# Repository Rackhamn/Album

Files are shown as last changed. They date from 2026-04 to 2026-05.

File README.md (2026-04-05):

<picture align="center">
  <source media="(prefers-color-scheme: dark)" srcset="/img/Album_logo_demo_dark.png">
  <source media="(prefers-color-scheme: light)" srcset="/img/Album_logo_demo_light.png">
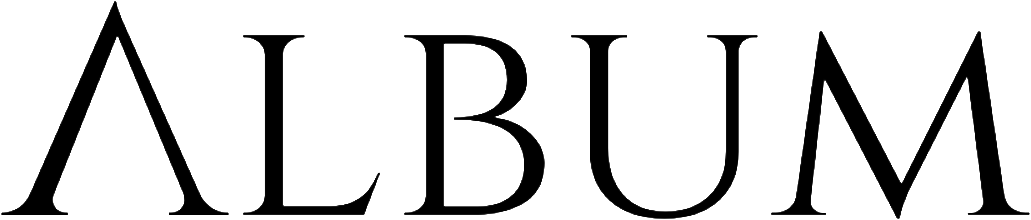
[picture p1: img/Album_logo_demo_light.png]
[Album Logo Demo]
  
</picture>

# ALBUM
Album is a handwired 36-key split keyboard with a custom firmware for the Atmega32u4 MCU.  
> Specifically Adafriut's ItsyBitsy Atmega32u4 16MHz 5V version found [here](https://www.adafruit.com/product/3677).  
  
It has a column-stagger with each half having two thumb keys and a [TOTEM](https://github.com/GEIGEIGEIST/TOTEM) inspired pinky key.  
The inital version did have a significant splay on the outer columns and the thumb keys, however my 3D printer had enough issues with layer shifting and thus I had to simplify it for V1.  
  
Album firmware currently runs the master code on the `LEFT` and the slave on the `RIGHT`.  
Master can be connected to any computer over the Atmega32u4 Micro-B port.  
The master and the slave parts can be connected over the TRRS jack.  
  
The Album firmware does not plan to rival others like [QMK](https://github.com/qmk/qmk_firmware), instead it was a challenging but fun process to plan and build out the features that I personally wanted to use.  
A previous `DEMO` version used a single 3x3 macro-pad style keyboard and a [VIAL](https://github.com/vial-kb/vial-qmk)-like keymap updater (through the USB-HID Vendor Reports) that does not need to compile or re-flash the firmware just to update a single keymap value change. It recieved a correct HID Report in a format according to a very simple protocol and overwrote the keymap in `SRAM` but also the stored keymap in `EEPROM`.  
*Very nice*.  
  
I am working on the new version for the V1 release and so far it seems very promising!  

## On the Source  
This is a final project for an __IoT- and Embedded Systems Degree__, the final source will be published at the end of the project.  
The source code will be come with the corresponding dependencies and build scripts for compiling everything along with the USB layer/keymap/macro updater scripts.  
  
## Case and Materials  
The `STL` files can be found [here](/case/).  
The bill-of-materials can be found here `link`.  
  
## Photos  
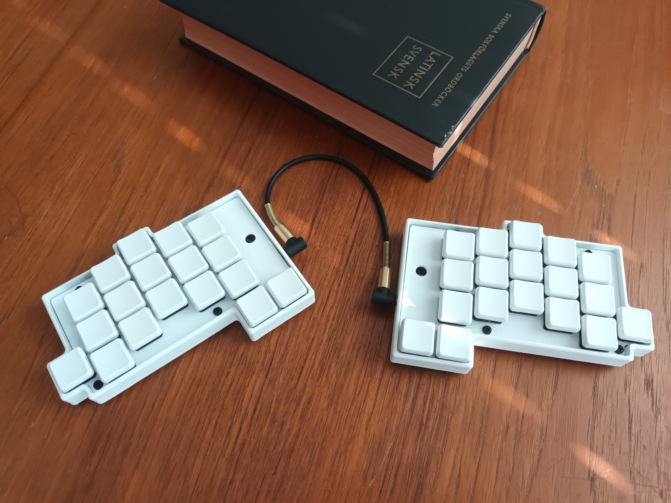
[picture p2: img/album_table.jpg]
Album on Wooden Table
  
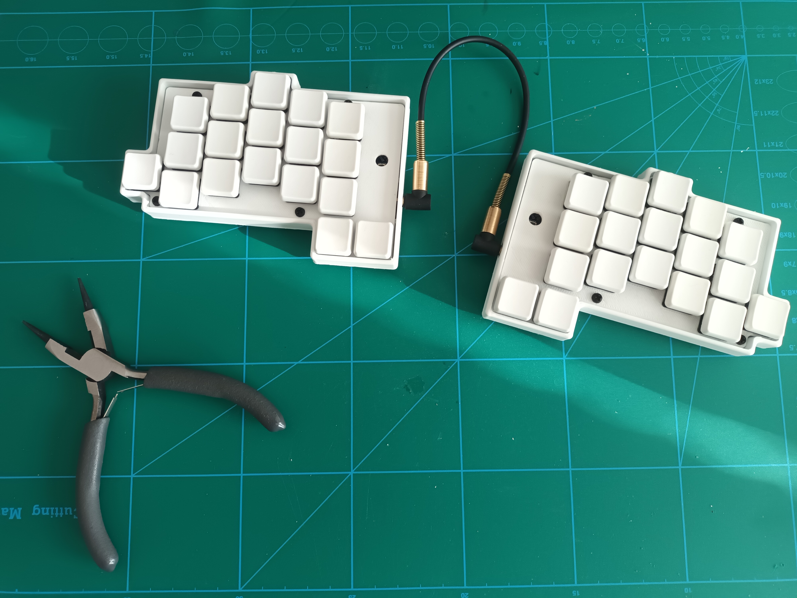
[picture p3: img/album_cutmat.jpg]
Album on Green Cutting Mat
  

## Credits
Really cool initial inspiration from the TOTEM keyboard in terms of visual design.  
[TOTEM Keyboard by GEIGEIGEIST](https://github.com/GEIGEIGEIST/TOTEM)  

Fantastic website with lots of references for keyboard design!  
[kbd.news](https://kbd.news)  
  
Great jumping off point to be able to start working on a deeper implementation of USB-HID on the Atmega32u4.  
[KMani314's Atmega32u4 HID Keyboard](https://github.com/kmani314/ATMega32u4-HID-Keyboard)  
  
Font is Cinzel-Regular by ndiscovered, you can download it [here](https://www.1001fonts.com/cinzel-font.html)  

Switch and Keycaps:  
[Switch (Kailh Choc low-profile white/clicky)](https://chosfox.com/products/kailh-chocs)  
[Keycaps (Choc low-profile 1U white)](https://chosfox.com/products/chocfox-cfx-choc-keycaps)  
> If you are going to make your own, I would recommend using slient tactile switches instead. The clicky ones are slightly echo-y in the V1 case unless you add support foam etc...

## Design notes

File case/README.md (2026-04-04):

# About the Case and Plate Housing
  
The case is built of two pieces, one bottom-side and a inner-top part.  
This case was 3D printed with a PLA printer at 4mm with 'regular' white PLA.  
I would recommend that you use a resin printer for cleaner results.  
> My printer did have issues with the wall sizes, and a couple of inner supports got broken during the printing process.  
  
To get either the left or right version, you can put them into you slicer of choice and invert the X-axis of the models.  

*[images here]*

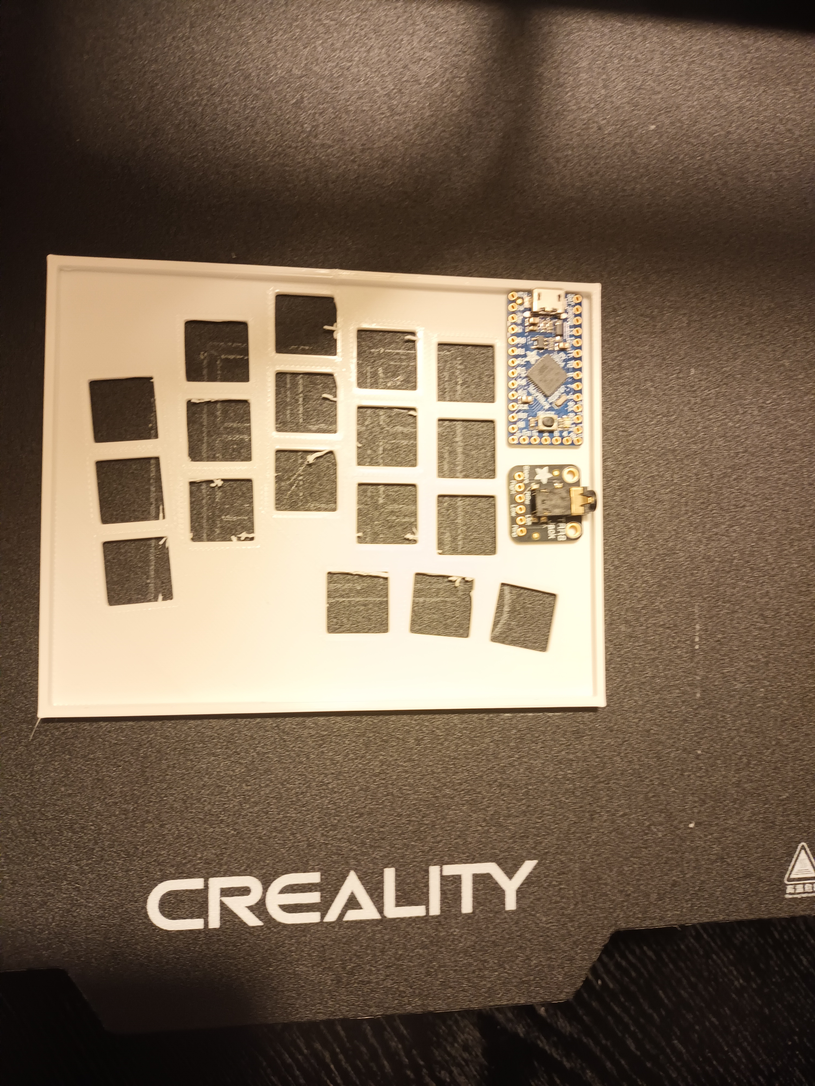
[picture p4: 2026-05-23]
img/proto/layout_pv0.jpg

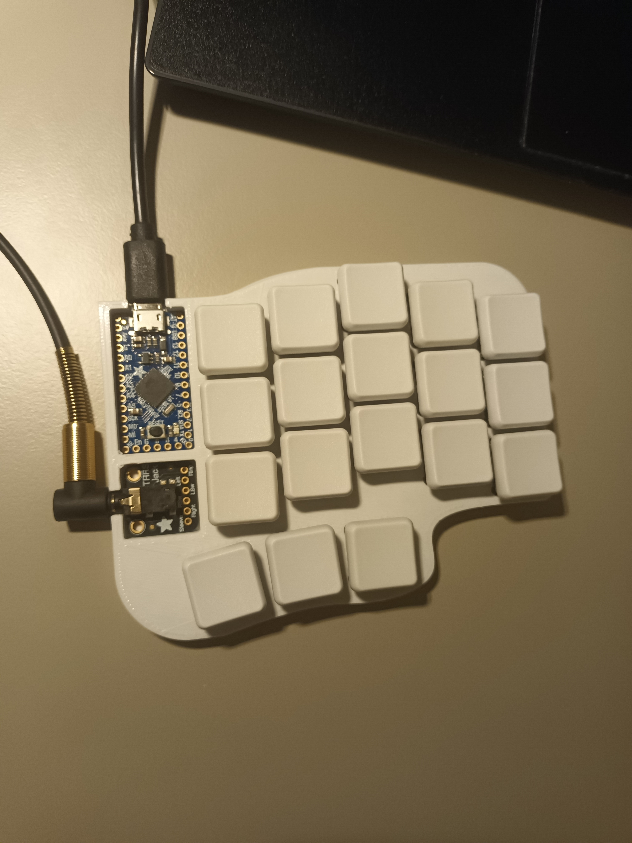
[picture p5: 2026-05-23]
img/proto/layout_pv1.jpg

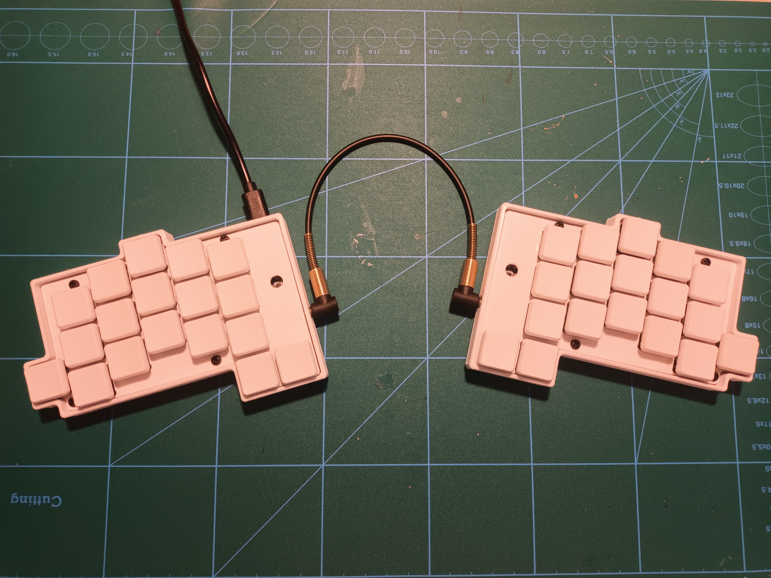
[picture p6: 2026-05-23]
img/proto/final_conn.jpg

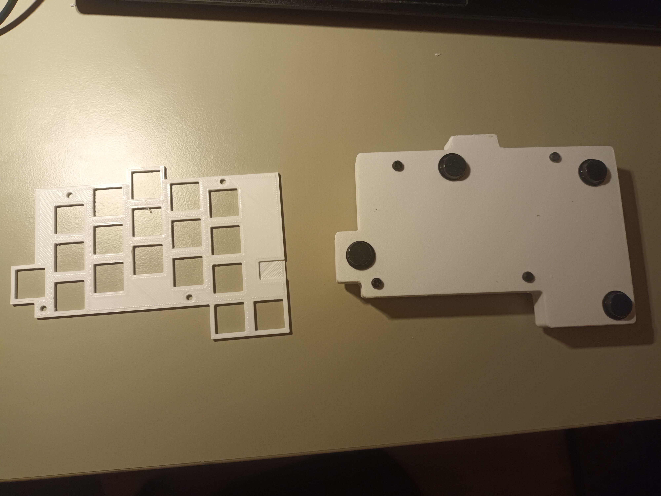
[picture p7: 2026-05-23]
img/proto/layout_pv4_case.jpg

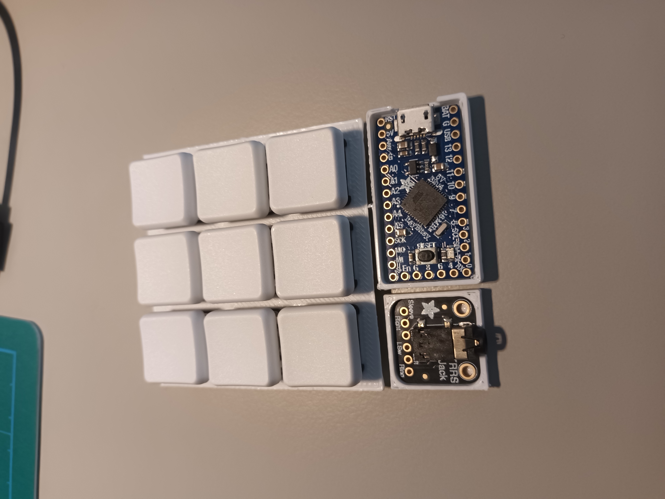
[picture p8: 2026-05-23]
img/proto/layout_pvx.jpg

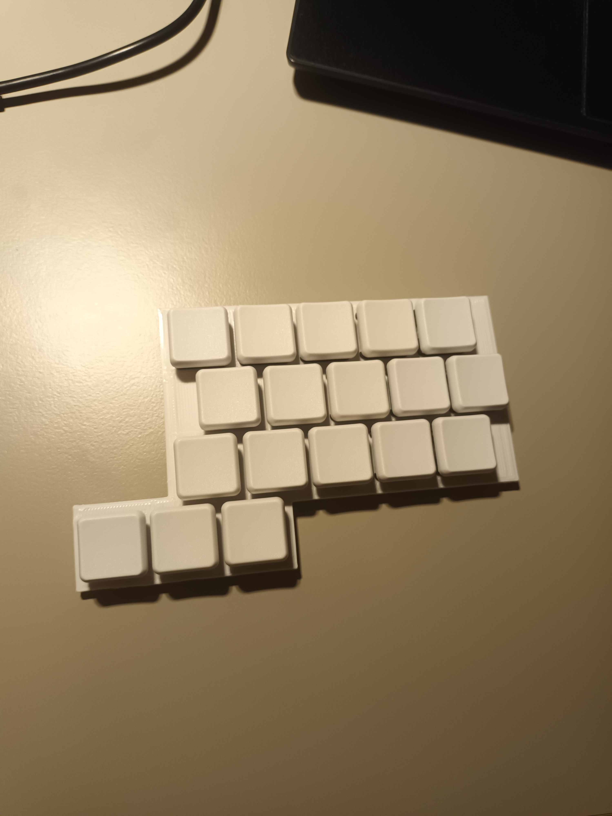
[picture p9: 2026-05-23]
img/proto/layout_pv3.jpg

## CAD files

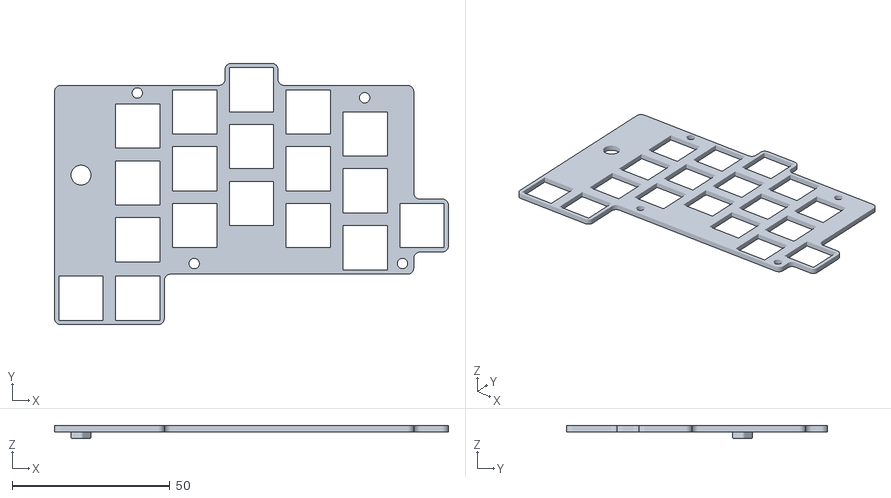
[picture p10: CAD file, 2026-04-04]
case/album_plate.stl
124.8 x 82.8 x 4.00

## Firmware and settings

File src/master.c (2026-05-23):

#ifndef F_CPU
#define F_CPU 16000000UL
#endif

#include <avr/io.h>
#include <util/delay.h>
#include <avr/interrupt.h>
#include <avr/eeprom.h>
#include <string.h> // memcpy

#include "types.h" // todo: replace NintM_t with NM
#include "macros.h"
#include "defs.h"

#include "usb.h"
#include "usb.c"

#include "crc8.c"

#include "keycodes.h"
#include "keybase.h"

// for both halfs!
u8 matrix[KEYMAP_LAYER_SIZE] = { 0 };
u8 last_matrix[KEYMAP_LAYER_SIZE] = { 0 };

#define NUM_LAYERS	2
#define KEYBOARD_DATA_LAYERS \
	[0]{																															\
	/* Base Layer: */																											\
		/* Master */																											\
		K(KC_Q), K(KC_W), K(KC_E), K(KC_R), K(KC_T),																			\
		K(KC_A), K(KC_S), K(KC_D), K(KC_F), K(KC_G),																			\
		K(KC_Z), K(KC_X), K(KC_C), K(KC_V), K(KC_B),																			\
		K(KC_Y), 0x00, 0x00, K(KC_O), DK(KEY_DEV_LAYER_INC),																	\
																																\
		/* Slave */																												\
		K(KC_Q), K(KC_W), K(KC_E), KM(KC_8, MOD_RIGHT, MOD_ALT), KM(KC_9, MOD_RIGHT, MOD_ALT),									\
		K(KC_A), K(KC_S), K(KC_D), K(KC_F), K(KC_G),																			\
		K(KC_Z), K(KC_X), K(KC_C), K(KC_V), K(KC_B),																			\
		DK(KEY_DEV_LAYER_DEC), K(KC_U), 0x00, 0x00, K(KC_P)																		\
	},																															\
	[1]{																															\
	/* Alt Layer: */																											\
		/* Master */																											\
		M(KC_MEDIA_BRIGHTNESS_DOWN), M(KC_MEDIA_BRIGHTNESS_UP), M(KC_MEDIA_MUTE), M(KC_MEDIA_VOL_DOWN), M(KC_MEDIA_VOL_UP),		\
		M(KC_MEDIA_BRIGHTNESS_MIN), K(KC_MEDIA_BRIGHTNESS_MAX), 0x00, M(KC_MEDIA_PLAY_PAUSE), 0x00,								\
		M(0xFF), K(KC_F), K(KC_J), K(KC_K), K(KC_L),																			\
		K(KC_Y), 0x00, 0x00, K(KC_O), DK(KEY_DEV_LAYER_INC),																	\
																																\
		/* Slave */																												\
		K(KC_Q), K(KC_W), K(KC_E), KM(KC_8, MOD_RIGHT, MOD_ALT), KM(KC_9, MOD_RIGHT, MOD_ALT),									\
		K(KC_A), K(KC_S), K(KC_D), K(KC_F), K(KC_G),																			\
		K(KC_Z), K(KC_X), K(KC_C), K(KC_V), K(KC_B),																			\
		DK(KEY_DEV_LAYER_DEC), K(KC_U), 0x00, 0x00, K(KC_P)																		\
	}

keyval_t matrix_vals[NUM_LAYERS][KEYMAP_LAYER_SIZE] = {
	KEYBOARD_DATA_LAYERS
};

// todo: rebuild into keyval_t data
typedef struct {
	u8 layer_index;
	u8 key_index;
	u16 repeat_ms;
	u32 last_sent_ms;
} hold_repeat_key_t;

// maybe add a minimum-hold time req. before we start to do the thing!
hold_repeat_key_t hold_repeat_keys[] = {
	{ 1, 3, 250, 0 },
	{ 1, 4, 250, 0 }
};
#define NUM_HOLD_REPEAT_KEYS (sizeof(hold_repeat_keys) / sizeof(hold_repeat_key_t))

hold_repeat_key_t * get_hold_repeat_key(u8 layer, u8 key) {
	for(u8 i = 0; i < NUM_HOLD_REPEAT_KEYS; i++) {
		if(hold_repeat_keys[i].layer_index == layer && hold_repeat_keys[i].key_index == key) {
			return &hold_repeat_keys[i];
		}
	}
	return NULL;
}

typedef struct keyboard_s {
	u8 num_layers;
	keyval_t (*map)[KEYMAP_LAYER_SIZE];

	// state
	u8 layer_index;
} keyboard_t;

keyboard_t keyboard = {
	.num_layers = NUM_LAYERS, // sizeof(matrix_vals)/sizeof(matrix_vals[0]),
	.map = matrix_vals,
	.layer_index = 0
};

// TODO: not active in current version 0.9
typedef struct __attribute__((packed)) {
	u8 magic;
	keyval_t keys[NUM_LAYERS][KEYMAP_LAYER_SIZE];
} keymap_config_t;

keymap_config_t ee_keymap EEMEM = {
	.magic = EEPROM_MAGIC,
	.keys = { KEYBOARD_DATA_LAYERS }
};

#if 0
keymap_config_t rt_keymap = {
	.magic = EEPROM_MAGIC,
	.keys = { KEYBOARD_DATA_LAYERS }
};

void load_keymap(void) {
	eeprom_read_block(&rt_keymap, &ee_keymap, sizeof(keymap_config_t));
	// eeprom_read_block(&rt_keymap, (const void*)EEPROM_ADDR, sizeof(keymap_config_t));

	#if 1
	if(rt_keymap.magic != EEPROM_MAGIC) {
		// TODO: handle both halfs
		memcpy(rt_keymap.keys, matrix_vals, NUM_LAYERS * KEYMAP_LAYER_SIZE);
		rt_keymap.magic = EEPROM_MAGIC;
		eeprom_write_block(&rt_keymap, &ee_keymap, sizeof(keymap_config_t));
		// eeprom_write_block(&rt_keymap, (void*)EEPROM_ADDR, sizeof(keymap_config_t));
	}
	#endif
	
	memcpy(matrix_vals, rt_keymap.keys, NUM_LAYERS * KEYMAP_LAYER_SIZE);
}

#if 0
// TODO: make eeprom writing be per-iteration (partially deffered)
// so write one byte per iteration instead of blocking by writing all at once?
void handle_hid_feature(void) {
	// return;

	if(!vendor_out_ready) { 
		return; 
	} else {
		vendor_out_ready = 0;
	}

	if(vendor_out_buf[0] != EEPROM_MAGIC) {
		return;
	}

	for(u8 i = 0; i < KEYMAP_LAYER_SIZE; i++) {
		rt_keymap.keys[i] = vendor_out_buf[i + 1];
	}

	memcpy(matrix_vals, rt_keymap.keys, KEYMAP_LAYER_SIZE);
	eeprom_write_block(&rt_keymap, &ee_keymap, sizeof(keymap_config_t));
}
#endif
#endif

void uart_init(void) {
	ENABLE_INPUT(RX_PIN);
	ENABLE_OUTPUT(TX_PIN);

	#if 1
	// Asynchronous normal mode (U2Xn = 0)
	// unsigned short baud_rate = ((F_CPU / (16UL * UART_BAUD)) - 1);

	UCSR1A = (1 << U2X1); // enable double speed
	unsigned short baud_rate = ((F_CPU / (8UL * UART_BAUD)) - 1);
	
	// baud rate 9600 @ 16MHz
	UBRR1H = (unsigned char)(baud_rate >> 8);
	UBRR1L = (unsigned char)(baud_rate & 0xFF);

	// UCSR1B = (1 << RXEN1) | (1 << TXEN1) | (1 << RXCIE1); // | (1 << TXCIE1);
	UCSR1B = (1 << RXEN1) | (1 << TXEN1) | (1 << RXCIE1);

	// 8N1 frame format
	UCSR1C = (1 << UCSZ11) | (1 << UCSZ10);
	#else
	// instead of using the calculated baudrate, use the one that gives the lowest error (0.2% vs 2.1%)
	// UCSR1A = (1 << U2X1); // double speed mode
	// UBBR1 = 16; // 115200 baud @ 16MHz in double speed mode
	// math: F_CPU / (8UL * UART_BAUD) - 1

	UCSR1A = (1 << U2X1); 
	UBRR1 = 16;

	// UDRIEn
	// enable txrx irq
	UCSR1B = (1 << RXEN1) | 
			 (1 << TXEN1) | 
			// (1 << TXCIE1) | 
			 (1 << RXCIE1);

	// set 8-bit data, 0 parity, 1 stop bit
	UCSR1C = (1 << UCSZ10) | (1 << UCSZ11);
	#endif
}

#define UART_RX_QUEUE_SIZE		(UART_QUEUE_SIZE)
volatile u8 uart_rxq[UART_RX_QUEUE_SIZE] = { 0 };
volatile u8 uart_rx_head = 0;
volatile u8 uart_rx_tail = 0;

static inline int uart_rx_pop(void) {
	if(uart_rx_tail == uart_rx_head) return -1;
	u8 byte = uart_rxq[uart_rx_tail];
	uart_rx_tail = (uart_rx_tail + 1) % UART_RX_QUEUE_SIZE;
	return byte;
}

volatile u8 slave_matrix[NUM_KEYS_PER_HALF] = { 0 };
volatile u8 slave_packet_ready = 0;

// TODO: move into timing.c/h
volatile u32 g_ms = 0;
u32 millis(void) {
	u32 ms;
	cli();
	ms = g_ms;
	sei();
	return ms;
}

void unpack_slave_matrix(u8 * slave_packet, u8 * out) {
	for(u8 i = 0; i < NUM_KEYS_PER_HALF; i++) {
		out[i] = 0;
	}

	for(u8 i = 0; i < NUM_KEYS_PER_HALF; i++) {
		u8 byte = slave_packet[2 + (i >> 3)];
		u8 bit = i & 7;
		out[i] = (byte >> bit) & 1;
	}
}

u8 handled_uart_packet_timer = 0;
u8 handled_uart_packet = 0;
void handle_slave_packet(u8 * packet) {
	// read slave matrix state (3x bits into 4x5 bytes after each master row)
	if(packet[0] == UART_START && packet[1] == UART_MSG_KEYMAP) {
		if(packet[5] != calc_crc8(&packet[2], 3)) {
			return;
		}
		unpack_slave_matrix(packet, (u8*)slave_matrix);
		slave_packet_ready = 1;
	}
}

void process_uart_packets(void) {
	static u8 rx_pos = 0;
	static u8 packet[UART_PACKET_SIZE] = { 0 };
	static u32 last_byte_time = 0;
	// if(slave_packet_ready) return;

	u32 now = millis();
	
	// if we are in mid-packet and havnt rxd byte in 50ms - rest
	if(rx_pos > 0 && (now - last_byte_time) > 50) {
		// timeout or resync
		rx_pos = 0;
	}
	
	int byte;
	while((byte = uart_rx_pop()) >= 0) {
		last_byte_time = millis();

		// restart always if we see START byte for framing fix
		if(byte == UART_START && rx_pos != 0 && rx_pos != 1) {
			rx_pos = 0;
		}

		switch(rx_pos) {
			case 0: {
				if(byte == UART_START) {
					packet[0] = byte;
					rx_pos = 1;
				}
			} break;
			case 1: {
				if(byte == UART_MSG_KEYMAP) {
					packet[1] = byte;
					rx_pos = 2;
				} else {
					// restart / desync
					rx_pos = 0;
				}
			} break;
			default: {
				packet[rx_pos++] = byte;
				if(rx_pos >= UART_PACKET_SIZE) {
					handle_slave_packet(packet);
					rx_pos = 0;
				}
			} break;
		}
	}
}

ISR(USART1_RX_vect) {
	u8 status = UCSR1A;
	// Must read UDR1 to clear error flags
	u8 byte = UDR1;
	
	// Check for errors
	if(status & ((1 << FE1) | (1 << DOR1) | (1 << UPE1))) {
		// Discard corrupted byte, but error flags are now cleared
		SET_PIN_HIGH(EXT_LED2_PIN);
		return;
	}
	
	u8 next_head = (uart_rx_head + 1) % UART_RX_QUEUE_SIZE;
	if(next_head != uart_rx_tail) {
		// not full
		uart_rxq[uart_rx_head] = byte;
		uart_rx_head = next_head;
	} else {
		// drop byte
		SET_PIN_HIGH(EXT_LED2_PIN);
	}
}

// TODO: remake to handle master and slave halves!
u8 p2i(u8 col, u8 row) {
	// return (row * (COLS + COLS)) + col;
	return (row * COLS) + col;
}

void init_matrix(void) {
	// TODO: make this work from a list of pins (given by user)
	ENABLE_OUTPUT(ROW_0_PIN);
	ENABLE_OUTPUT(ROW_1_PIN);
	ENABLE_OUTPUT(ROW_2_PIN);

		ENABLE_OUTPUT(ROW_3_PIN);

	SET_PIN_HIGH(ROW_0_PIN);
	SET_PIN_HIGH(ROW_1_PIN);
	SET_PIN_HIGH(ROW_2_PIN);

		SET_PIN_HIGH(ROW_3_PIN);

	ENABLE_INPUT(COL_0_PIN);
	ENABLE_INPUT(COL_1_PIN);
	ENABLE_INPUT(COL_2_PIN);

		ENABLE_INPUT(COL_3_PIN);
		ENABLE_INPUT(COL_4_PIN);

	#if 1
	PULLUP_PIN(COL_0_PIN);
	PULLUP_PIN(COL_1_PIN);
	PULLUP_PIN(COL_2_PIN);

		PULLUP_PIN(COL_3_PIN);
		PULLUP_PIN(COL_4_PIN);
	#endif

	// force re-enable pullups
	SET_PIN_HIGH(COL_0_PIN);
	SET_PIN_HIGH(COL_1_PIN);
	SET_PIN_HIGH(COL_2_PIN);

		SET_PIN_HIGH(COL_3_PIN);
		SET_PIN_HIGH(COL_4_PIN);
}

void scan_master_matrix(void) {
	// TODO: make this work from a list of pins (given by user)
	// or even generated in a pre-pass
	for(u8 row = 0; row < ROWS; row++) {
		// activate
		switch(row) {
			case 0: SET_PIN_LOW(ROW_0_PIN); break;
			case 1: SET_PIN_LOW(ROW_1_PIN); break;
			case 2: SET_PIN_LOW(ROW_2_PIN); break;
			case 3: SET_PIN_LOW(ROW_3_PIN); break;
		}

		_delay_us(SCAN_DELAY);

		// maybe should be half?
		matrix[p2i(0, row)] = (READ_PIN(COL_0_PIN) == 0);
		matrix[p2i(1, row)] = (READ_PIN(COL_1_PIN) == 0);
		matrix[p2i(2, row)] = (READ_PIN(COL_2_PIN) == 0);
		matrix[p2i(3, row)] = (READ_PIN(COL_3_PIN) == 0);
		matrix[p2i(4, row)] = (READ_PIN(COL_4_PIN) == 0);

		// deactivate
		switch(row) {
			case 0: SET_PIN_HIGH(ROW_0_PIN); break;
			case 1: SET_PIN_HIGH(ROW_1_PIN); break;
			case 2: SET_PIN_HIGH(ROW_2_PIN); break;
			case 3: SET_PIN_HIGH(ROW_3_PIN); break;
		}
	}
}

void merge_matrix(void) {
	#if 0
	// merge slave and master matrix data
	for(u8 row = 0; row < ROWS; row++) {
		for(u8 col = 0; col < COLS; col++) {
			u8 sval = slave_matrix[(row * COLS) + col];
			matrix[(row * (COLS * 2)) + COLS + col - 1] = sval;
		}
	}
	#else
	// linear merge
	for (u8 i = 0; i < NUM_KEYS_PER_HALF; i++) {
        matrix[NUM_KEYS_PER_HALF + i] = slave_matrix[i];
    }
	#endif
}

void send_matrix(void) {
	SET_PIN_LOW(EXT_LED2_PIN);
	u32 now = millis();

	// if we want transparent layer keys, this needs to be handled in the loop
	// get_next_layer_index(index, dir);
	keyval_t * layer_map = keyboard.map[keyboard.layer_index];

	keyval_t kv;
	for(u16 i = 0; i < KEYMAP_LAYER_SIZE; i++) {
		// send keypress events
		kv = layer_map[i];
		if(kv != 0) {
			u8 type = KEY_GET_TYPE(kv);
			u8 keycode = KEY_GET_VAL(kv);
			u8 modifiers = KEY_GET_MOD(kv);
			if(KEY_GET_MODLR(kv)) { 
				modifiers <<= 4;
			}

			if((matrix[i] == 1) && (last_matrix[i] == 0)) {
				if(type == KEY_TYPE_KEY) {
					send_keypress(keycode, modifiers);
				} else if (type == KEY_TYPE_MEDIA) {
					// TODO: add all media keys correctly in the keymap bits
					// M(0xFF) -> KC_MEDIA_AL_CALC
					if(keycode == 0xFF) {
						send_consumer_key(0x192);
					}
					else
						send_consumer_key(keycode);
				} else if (type == KEY_TYPE_DEV) {
					// TODO: use minmax or clamp?
					switch(keycode) {
						case KEY_DEV_LAYER_INC: {
							if((keyboard.layer_index + 1) < keyboard.num_layers) {
								keyboard.layer_index++;
							}
						} break;
						case KEY_DEV_LAYER_DEC: {
							if(keyboard.layer_index > 0) {
								keyboard.layer_index--;
							}
						} break;
					}
				}
			} else if((matrix[i] == 1) && (last_matrix[i] == 1)) {
				// dont like this call structure
				hold_repeat_key_t * hrkp = get_hold_repeat_key(keyboard.layer_index, i);

				// this double sends once because we dont set the last_sent_ms in prev.
				if(hrkp) {
					if((now - hrkp->last_sent_ms) >= hrkp->repeat_ms) {
						hrkp->last_sent_ms = now;

						if(type == KEY_TYPE_KEY) {
							send_keypress(keycode, modifiers);
						} else if (type == KEY_TYPE_MEDIA) {
							send_consumer_key(keycode);
						}
					}
				}
			}
		}
	}

	for(u16 i = 0; i < KEYMAP_LAYER_SIZE; i++) {
		last_matrix[i] = matrix[i];
	}
}

volatile u32 ms_counter = 0;
volatile u32 last_led_toggle = 0;
volatile u16 led_period = 500; // ms

ISR(TIMER0_COMPA_vect) {
	g_ms++;
	ms_counter++;
	if((ms_counter - last_led_toggle) >= led_period) {
		last_led_toggle = ms_counter;
		TOGGLE_PIN(LED_PIN);
	}
}

volatile u32 last_scan_ms = 0;
int main(void) {
	ENABLE_OUTPUT(EXT_LED2_PIN);
	SET_PIN_HIGH(EXT_LED2_PIN);

	usb_init();
	uart_init();
	
	// DDRC |= (1 << LED_PIN);
	ENABLE_OUTPUT(LED_PIN);
	SET_PIN_LOW(LED_PIN);
	
	for(u8 i = 0; i < NUM_KEYS_PER_HALF; i++) { slave_matrix[i] = 0; }
	for(u8 i = 0; i < KEYMAP_LAYER_SIZE; i++) { matrix[i] = last_matrix[i] = 0; }
	
	// TODO: init after USB is confirmed?
	init_matrix();
	// load_keymap();

	sei(); // enable global interrupts

	// TODO: use time counter to toggle led while waiting for usb
	while(!get_usb_config_status()) {
	// while(usb_kbd_configured() == 0) {
		TOGGLE_PIN(LED_PIN);
		TOGGLE_PIN(EXT_LED2_PIN);
		_delay_ms(50);
	}
	SET_PIN_LOW(LED_PIN);
	SET_PIN_LOW(EXT_LED2_PIN);

	// setup timer0 for 1ms ticks (for onboard LED)
	// NOTE: works with the TIMER0_COMPA_vect ISR
	TCCR0A = (1 << WGM01);				// CTC mode
	OCR0A = 249;						// 16MHz / (64 * (249 + 1)) = 1000Hz == 1ms
	TCCR0B = (1 << CS01) | (1 << CS00); // prescaler 64
	TIMSK0 = (1 << OCIE0A);				// enable compare match interrupt
	ms_counter = 0;
	// given that we use the timer0, should we wait until a certain "next max time?" or wait until comm. works and master tells slave to start LED?

	while (1) {
		// response from slave
		process_uart_packets();
		
		u32 now = millis();
		// 100hz scan rate
		if((now - last_scan_ms) >= 10) {
			last_scan_ms = now;

			// TODO: matrix scanning rate control
			if(slave_packet_ready) {
				merge_matrix();
				slave_packet_ready = 0;
			}
		}

		scan_master_matrix();
		send_matrix();
		
		// TODO: check / update this on IRQ timer?
		// handle_hid_feature();
		
		// Should this be here? maybe better if its only if usb state is idle?
		#if defined(SLEEP_TIME_MS) 
		#if SLEEP_TIME_MS > 0
		_delay_ms(1);
		#endif
		#endif
	}
}

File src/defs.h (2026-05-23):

#ifndef DEFS_H
#define DEFS_H

#ifndef F_CPU
#define F_CPU 16000000UL
#endif

#define UART_BAUD	115200
// #define UART_BAUD	9600
// #define UART_BAUD	38400

#define SCAN_DELAY	5
#define SHORT_DELAY	100
#define LONG_DELAY	500

// per keyboard half
#define ROWS				4
#define COLS				5

#define NUM_HALFS			2
#define NUM_KEYS_PER_HALF	(ROWS * COLS)
#define KEYMAP_LAYER_SIZE	(NUM_KEYS_PER_HALF * NUM_HALFS)

#define BITS_TO_BYTES(n)	(((n) + 7u) >> 3)
#define BITMAP_BYTES(bits)	((bits + 7) / 8)
#define KEYMAP_HALF_BYTES	BITMAP_BYTES(NUM_KEYS_PER_HALF)

// maybe not here?
#define EEPROM_MAGIC	0x42
#define EEPROM_ADDR		0x00

// TODO: maybe make uart packet COBS or use other format?
// UART_PACKET = [ START, MSG, LEN*, DATA[], CRC ] *LEN not in currently
// maybe also a SEQ number?
#define UART_QUEUE_SIZE		256
#define UART_START			0xAA
#define UART_MSG_KEYMAP		0xBB
#define UART_CRC_SIZE		1
#define UART_PACKET_SIZE	(1 + 1 + KEYMAP_HALF_BYTES + 1)

#define SLEEP_TIME_MS	10

// Pin 13 on Atmega32U4 ItsyBitsy 5V
#define LED_PIN		C, 7
#define EXT_LED_PIN	C, 6
#define EXT_LED2_PIN	F, 0

#define BTN_PIN		B, 5

// UART specifically - data lines are crossed in hardware!
#define TX_PIN		D, 3
#define RX_PIN		D, 2

// maybe reorder for master / slave?
#define COL_0_PIN	E, 6
#define COL_1_PIN	B, 5
#define COL_2_PIN	B, 6
#define COL_3_PIN	B, 7
#define COL_4_PIN	D, 6

#define ROW_0_PIN	F, 7
#define ROW_1_PIN	F, 6
#define ROW_2_PIN	F, 5
#define ROW_3_PIN	F, 4

#endif /* DEFS_H */

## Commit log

2026-04-04 Update README with Album keyboard information
    Expanded the README with detailed information about the Album keyboard, including its features, source code availability, materials, photos, and credits.
2026-04-04 Added case and plate for Album housing
    [album_plate.stl]
2026-04-04 Added info about Album housing
2026-04-04 Added link to Album housing
2026-04-04 Update README with keycaps/switch info
